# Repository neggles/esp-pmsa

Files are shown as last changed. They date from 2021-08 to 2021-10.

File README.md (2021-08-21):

# esp-pmsa


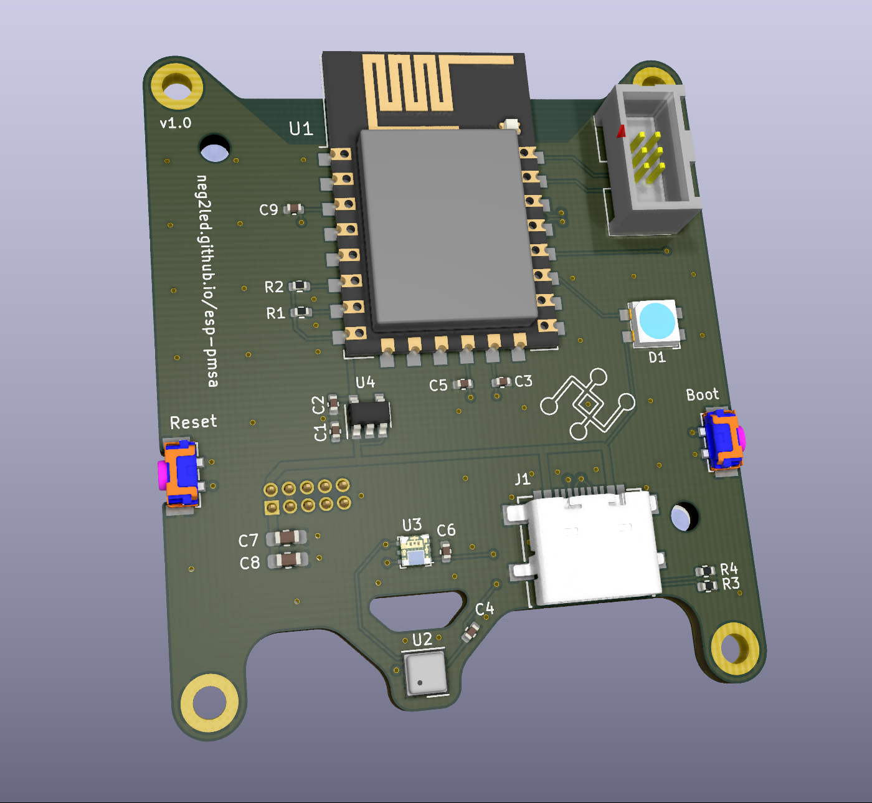
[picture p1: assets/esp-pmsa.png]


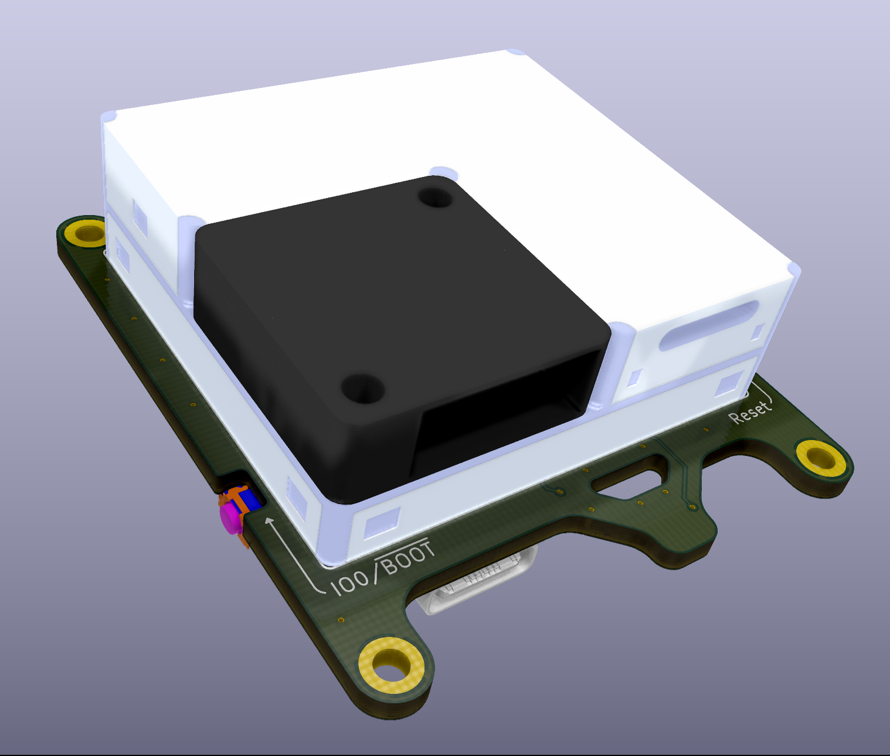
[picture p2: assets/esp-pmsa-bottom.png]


## Repository Structure
- `esp-pmsa` contains the main schematics and board drawing
- `esp-pmsa/esp-pmsa.pretty` contains the board-specific footprints
- `esp-pmsa/shapes3D` contains the 3D models for parts on the board (and a bunch of extras from my various experiments)

## Building
Simply call `make` in the top-top level directory. The `build` directory will then contain:

- the main board
- A panelized version of said board
- zipped gerbers for the boards you can directly use for manufacturing
- zipped gerbers and SMT assembly BOM/position files for JLCPCB's SMT assembly service for the single-board version.

Makefile uses [Jan Mrázek](https://github.com/yaqwsx)'s [KiKit](https://github.com/yaqwsx/KiKit), which I cannot recommend enough, and therefore has to be available on your system.

Jan's [jlcparts](https://yaqwsx.github.io/jlcparts/) app was also extremely useful in narrowing down part choices based on what JLCPCB have available.

-----
### **IMPORTANT NOTE:** If you give JLCPCB these files as-is, *please* verify the orientation of every part before submitting.

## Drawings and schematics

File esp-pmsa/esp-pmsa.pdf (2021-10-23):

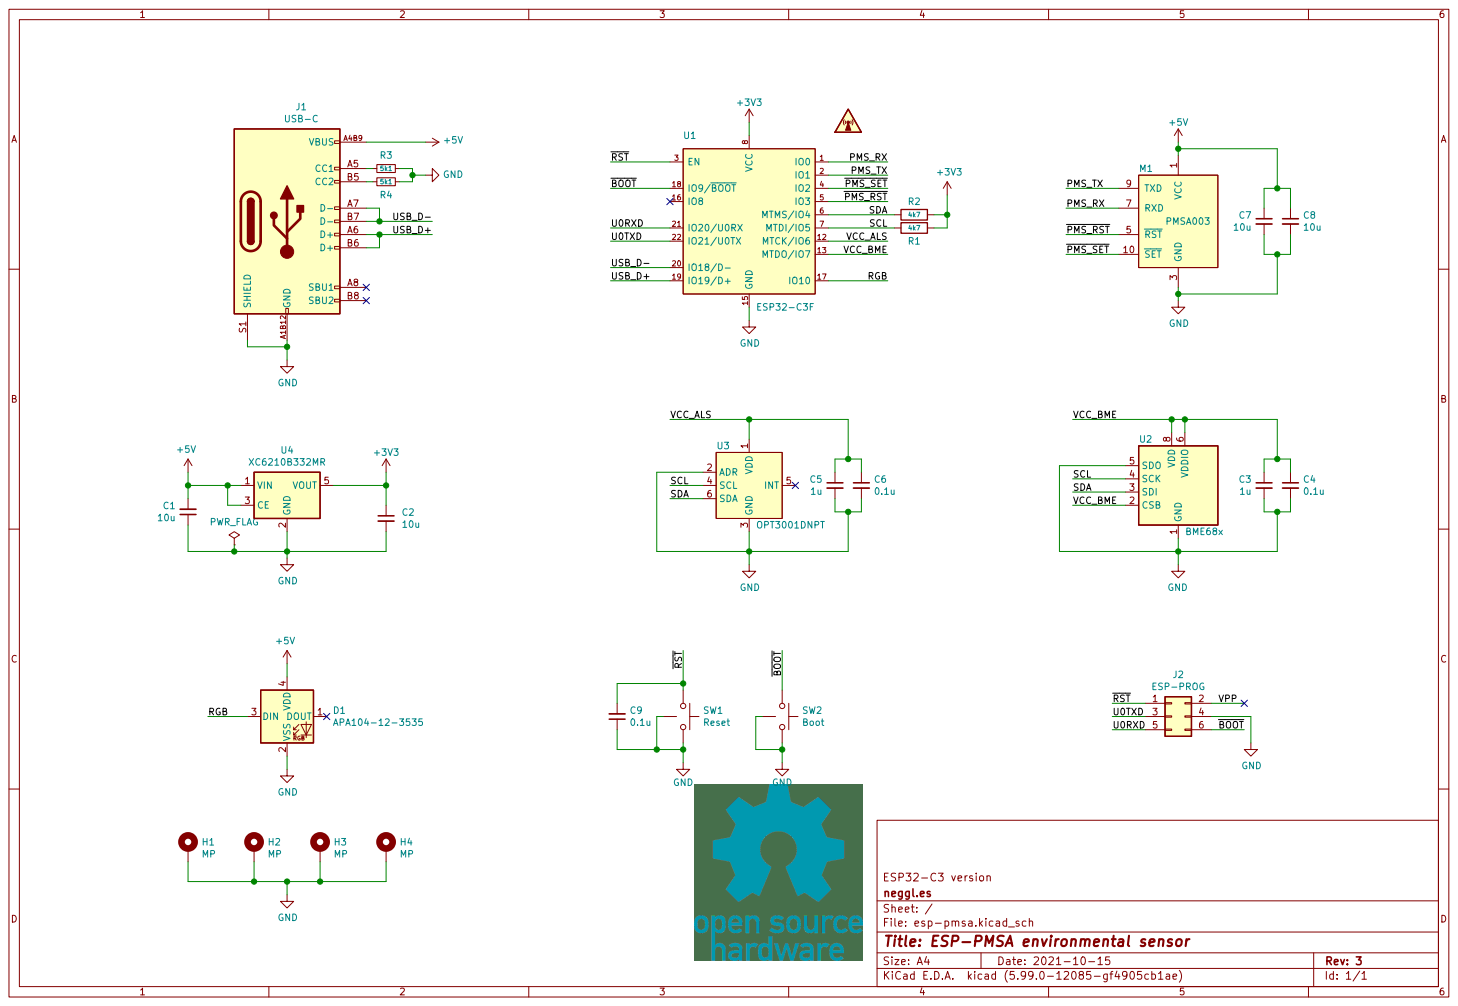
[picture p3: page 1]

3 ~{RST} 5 RXD 7 TXD 9 M1 PMSA003 GND

1 CSB 2 SDI 3 SCK 4 SDO 5 VDDIO

File: esp-pmsa.kicad_sch Sheet: / neggl.es ESP32-C3 version

Id: 1/1 Title: ESP-PMSA environmental sensor

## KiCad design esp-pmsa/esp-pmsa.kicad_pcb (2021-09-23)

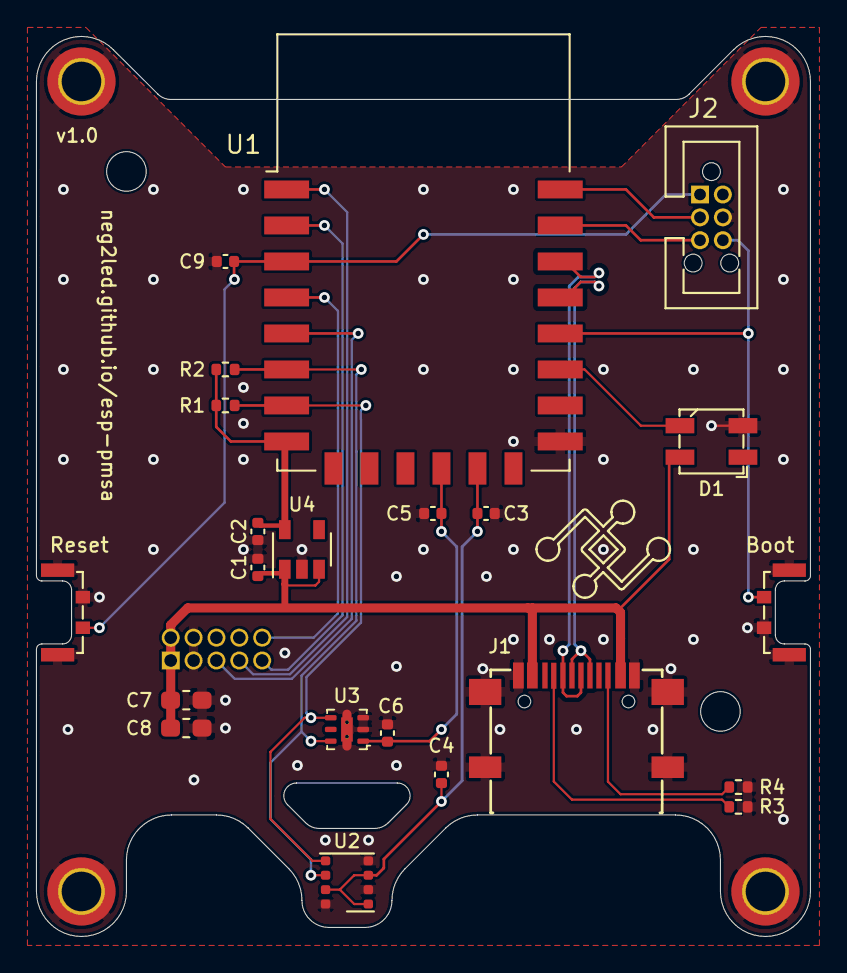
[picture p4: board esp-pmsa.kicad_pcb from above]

Board: 2 copper layers, 43.0 x 50.0 mm, 28 parts (1 on the bottom side), 20 nets.

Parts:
C1, C2: 10u; C_0402_1005Metric
C3, C5: 1u; C_0402_1005Metric
C4, C6, C9: 0.1u; C_0402_1005Metric
C7, C8: 10u; C_0603_1608Metric_Pad1.05x0.95mm_HandSolder
D1: APA104-12-3535; LED_APA104-12-3535
H1, H2, H3, H4: MP; MountingHole_2.2mm_M2_DIN965_Pad_TopBottom
J1: USB-C; USB-C-SMD_TYPEC-304S-ACP16
J2: ESP-PROG; TC2030_IDCBox_2x03_P1.25mm_Vertical_3D
LOGO1: neggles logo; neggle-logo-0.12
M1: PMSA003
R1, R2: 4k7; R_0402_1005Metric
R3, R4: 5k1; R_0402_1005Metric
SW1: Reset; SW-SMD_SKSLLAE010-3D
SW2: Boot; SW-SMD_SKSLLAE010-3D
U1: ESP32-C3F; ESP-12H
U2: BME68x; Bosch_LGA-8_3x3mm_P0.8mm_ClockwisePinNumbering
U3: OPT3001DNPT; MultiALS-LTR303-TIOPT3K
U4: XC6210B332MR; SOT-23-5

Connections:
+3V3: C2.1, R1.1, R2.1, U1.8 (VCC), U4.5 (VOUT)
+5V: C1.2, C7.1, C8.1, D1.4 (VDD), J1.A4B9 (VBUS), J1.B4A9 (VBUS), M1.1 (VCC), M1.2 (VCC), U4.1 (VIN), U4.3 (CE)
/PMS_RX: M1.7 (RXD), U1.1 (IO0)
/PMS_TX: M1.9 (TXD), U1.2 (IO1)
/RGB: D1.3 (DIN), U1.17 (IO10)
/SCL: R1.2, U1.7 (MTDI/IO5), U2.4 (SCK), U3.4 (SCL)
/SDA: R2.2, U1.6 (MTMS/IO4), U2.3 (SDI), U3.6 (SDA)
/U0RXD: J2.5, U1.21 (IO20/U0RX)
/U0TXD: J2.3, U1.22 (IO21/U0TX)
/USB_D+: J1.A6 (D+), J1.B6 (D+), U1.19 (IO19/D+)
/USB_D-: J1.A7 (D-), J1.B7 (D-), U1.20 (IO18/D-)
/VCC_ALS: C5.1, C6.1, U1.12 (MTCK/IO6), U3.1 (VDD)
/VCC_BME: C3.1, C4.1, U1.13 (MTDO/IO7), U2.2 (CSB), U2.6 (VDDIO), U2.8 (VDD)
/~BOOT: J2.6, SW2.2, U1.18 (IO9/~BOOT)
/~PMS_RST: M1.5 (~RST), U1.5 (IO3)
/~PMS_SET: M1.10 (~SET), U1.4 (IO2)
/~RST: C9.2, J2.1, SW1.2, U1.3 (EN)
GND: C1.1, C2.2, C3.2, C4.2, C5.2, C6.2, C7.2, C8.2, C9.1, D1.2 (VSS), H1.1, H2.1, H3.1, H4.1, J1.A1B12 (GND), J1.B1A12 (GND), J1.S1 (SHIELD), J2.4, M1.3 (GND), M1.4 (GND), R3.1, R4.1, SW1.1, SW1.MP, SW2.1, SW2.MP, U1.15 (GND), U2.1 (GND), U2.5 (SDO), U2.7 (GND), U3.2 (ADR), U3.3 (GND), U3.7 (GND), U4.2 (GND)
unnamed: J1.A5 (CC1), R3.2
unnamed: J1.B5 (CC2), R4.2

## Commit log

2021-04-13 still needs routing
    [esp-pmsa.kicad_pcb, esp-pmsa.sch]
2021-04-13 add gnd zones
    [esp-pmsa.kicad_pcb]
2021-04-14 ok this is silly
    [esp-pmsa.kicad_pcb, esp-pmsa.sch]
2021-04-15 still don't like
    [esp-pmsa.kicad_pcb]
2021-04-15 fix pour
    [esp-pmsa.kicad_pcb]
2021-08-11 switch to ESP-C3-F
    [esp-pmsa.kicad_pcb, esp-pmsa.sch]
2021-08-21 layout tweaks
    [esp-pmsa.kicad_pcb]
2021-08-21 okay that's better
    [esp-pmsa.kicad_pcb]
2021-09-23 update for kicad 6
    [esp-pmsa.kicad_pcb, esp-pmsa.kicad_sch]
2021-10-14 clean up old v5 files a bit, theres more i can delete
    [esp-pmsa.sch]
2021-10-23 actually built ver
    [esp-pmsa.kicad_sch]
2022-11-22 add .gitattributes
    [esp-pmsa.kicad_sch]
